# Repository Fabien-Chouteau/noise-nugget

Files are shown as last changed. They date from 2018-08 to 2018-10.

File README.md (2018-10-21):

# noise-nugget
Square Inch music widget

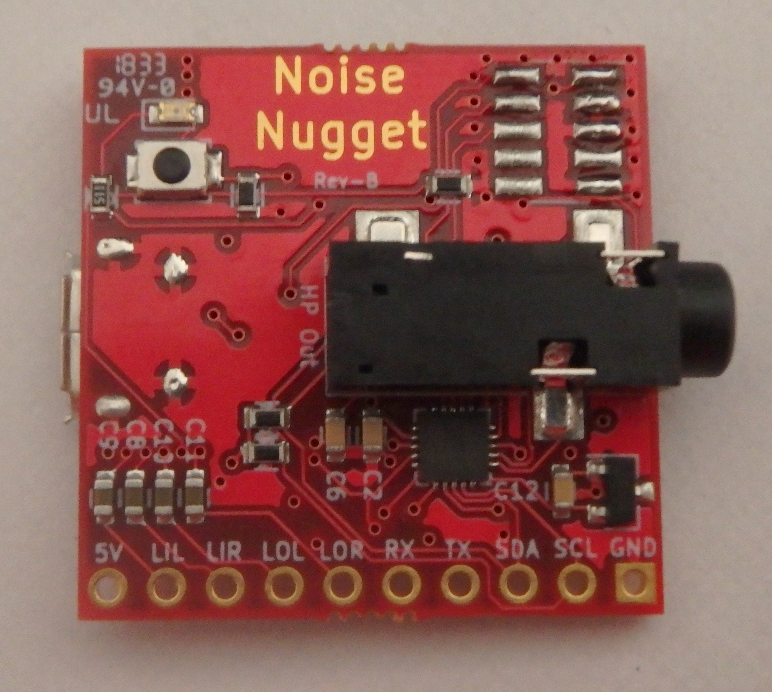
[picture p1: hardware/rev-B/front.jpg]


Noise Nugget is a compact digital synthesizer based on an 180MHz Cortex-M4 and
quality audio DAC with headphone amplifier.

My goal with this project is to create a little "Swiss Army knife" of audio
synthesis. Packing the maximum features on the smallest and cheapest board.

With all its connectivity (USB, 2 x audio out, 1 x audio in, I2C, UART, GPIOs)
it can be used for many different tasks:
 - Digital synthesizer, with a MIDI interface or some other means of control
 - Audio effects, for a guitar pedal or synthesizer (delay, reverb, distortion)
 - Audio FX trigger board, playing pre-recorded sounds
 - Audio playback, recording sounds from the input and then playing it back at
   the push of a button
 - USB sound interface

So far I implemented one audio effect, a MIDI over USB synth and sampler. Noise
Nugget is a compact digital synthesizer based on an 180MHz Cortex-M4 and
quality audio DAC with headphone amplifier.

My goal with this project is to create a little "Swiss Army knife" of audio
synthesis. Packing the maximum features on the smallest and cheapest board.

With all its connectivity (USB, 2 x audio out, 1 x audio in, I2C, UART, GPIOs)
it can be used for many different tasks:
- Digital synthesizer, with a MIDI interface or some other means of control
- Audio effects, for a guitar pedal or synthesizer (delay, reverb, distortion)
- Audio FX trigger board, playing pre-recorded sounds
- Audio playback, recording sounds from the input and then playing it back at
  the push of a button
- USB sound interface

So far I implemented one audio effect, a MIDI over USB synth and sampler.

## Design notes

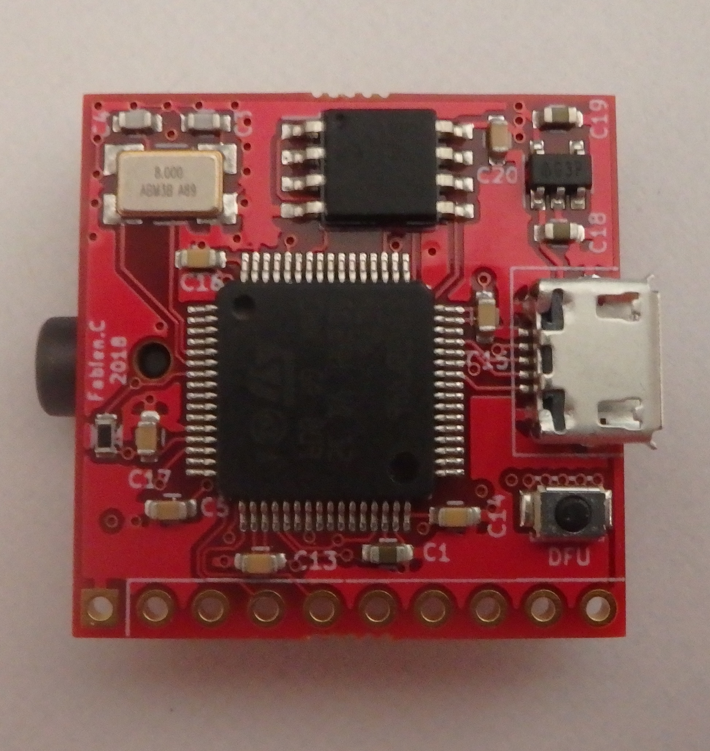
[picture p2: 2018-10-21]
hardware/rev-B/back.jpg

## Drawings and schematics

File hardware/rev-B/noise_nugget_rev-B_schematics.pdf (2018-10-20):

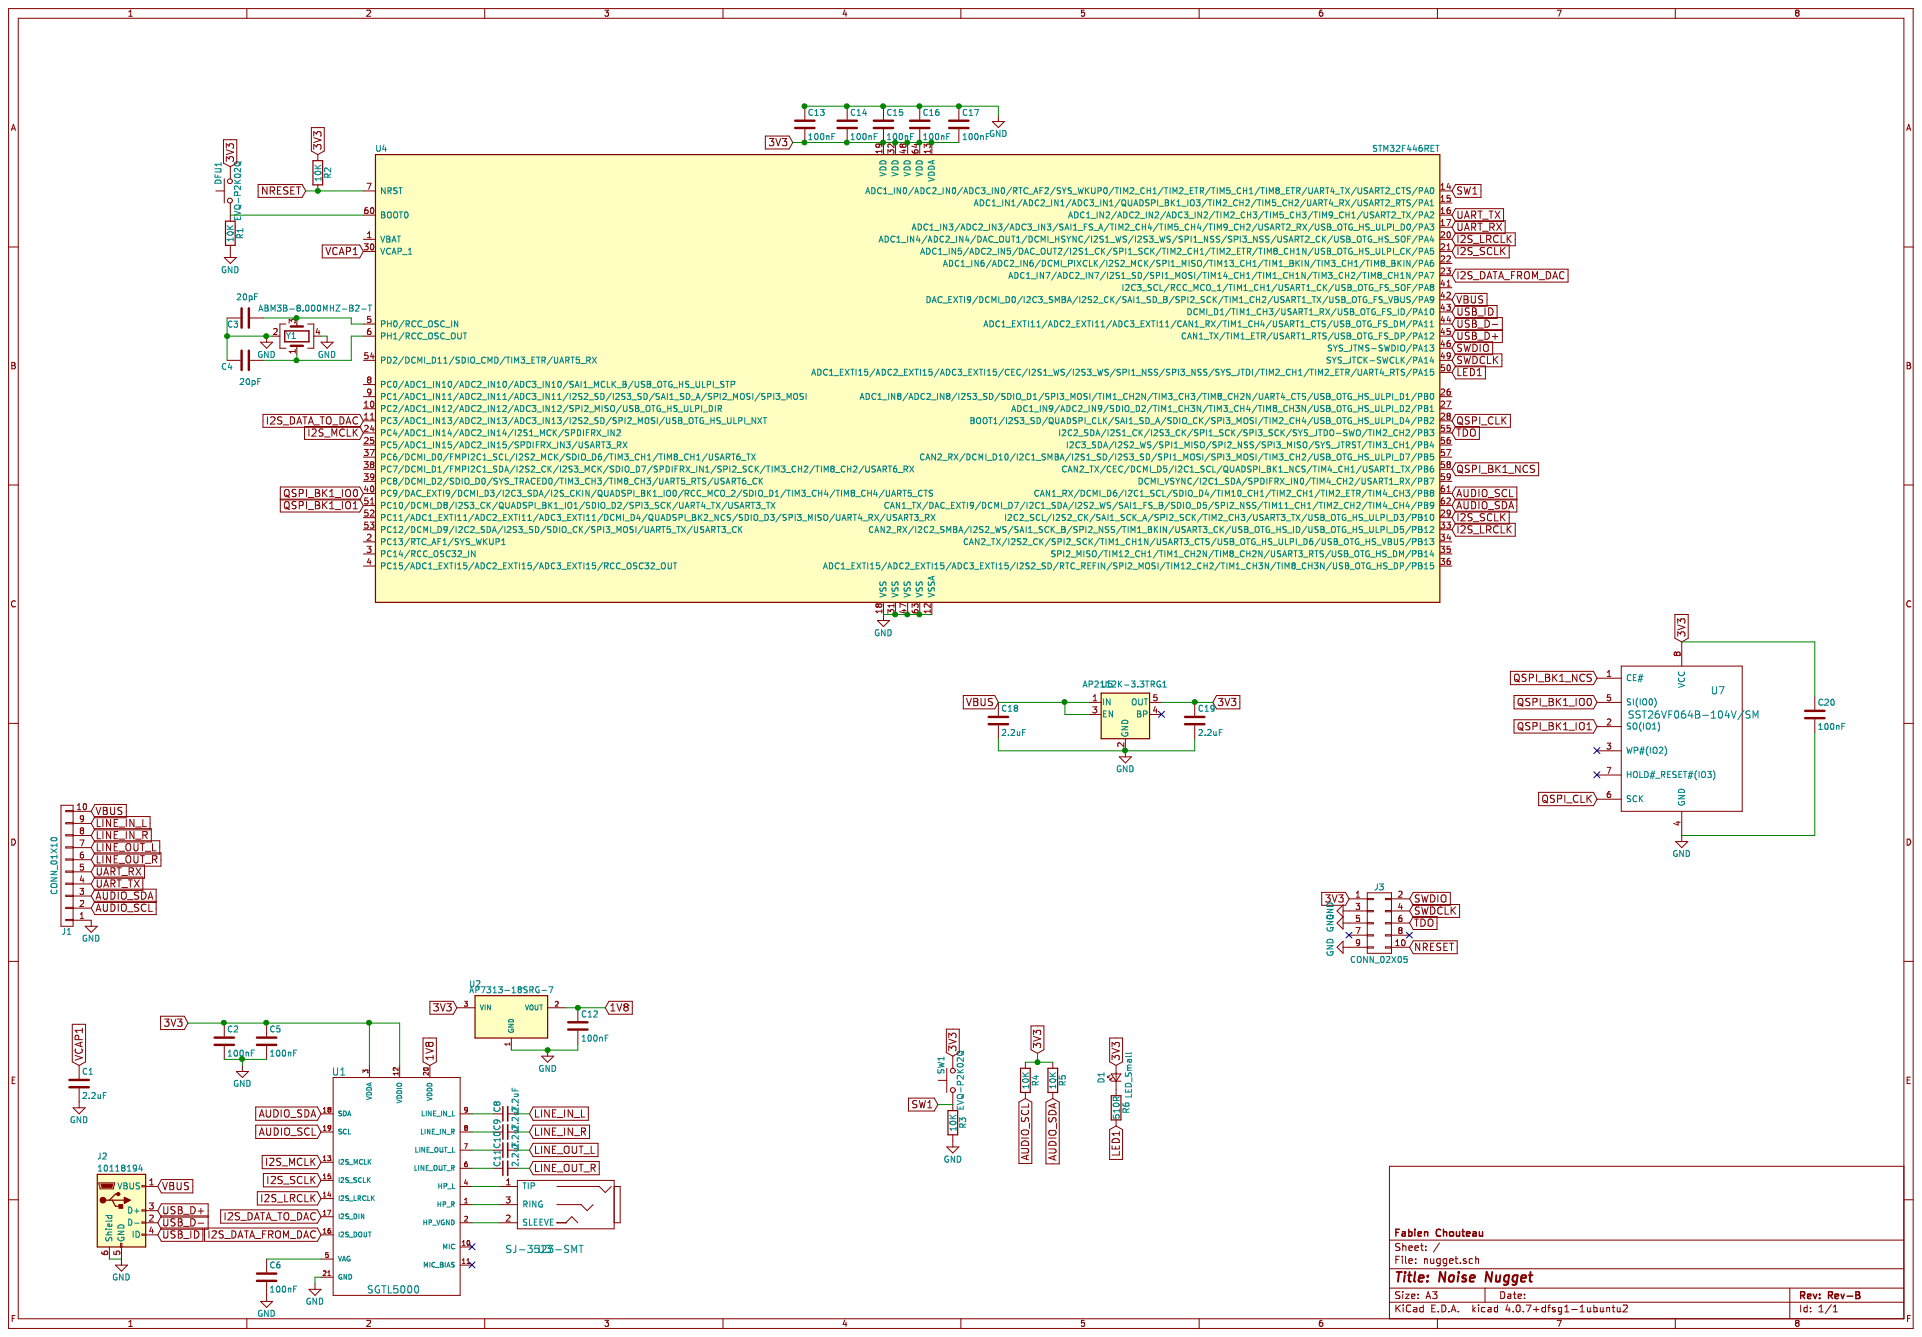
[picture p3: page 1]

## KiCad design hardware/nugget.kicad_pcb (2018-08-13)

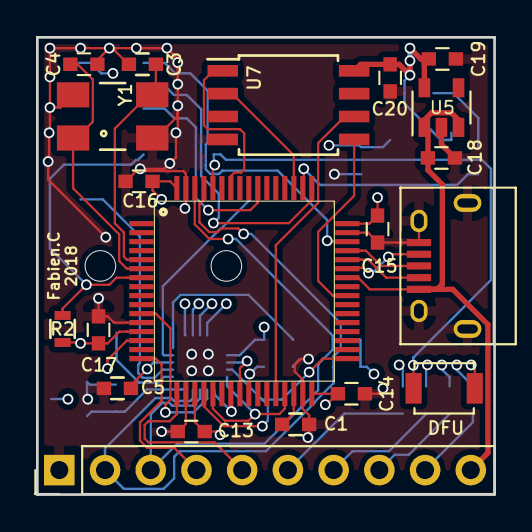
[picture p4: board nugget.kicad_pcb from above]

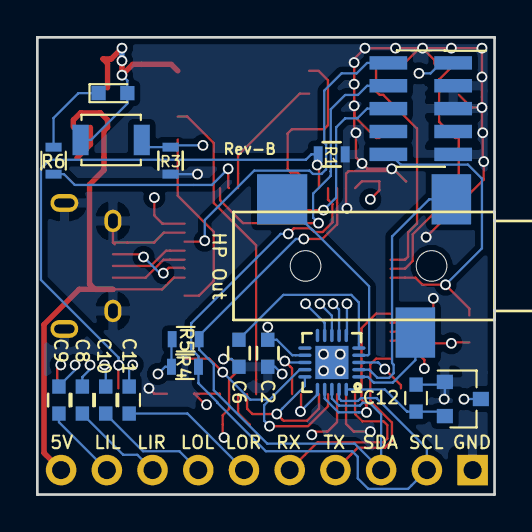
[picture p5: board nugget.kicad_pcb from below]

Board: 4 copper layers, 25.4 x 25.4 mm, 38 parts (18 on the bottom side), 43 nets.

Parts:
C1, C8, C9, C10, C11, C18, C19: 2.2uF; C_0603
C2, C5, C6, C12, C13, C14, C15, C16, C17, C20: 100nF; C_0603
C3, C4: 20pF; C_0603
D1: LED_Small; LED_0603
DFU1: EVQ-P2K02Q; SW_SPST_B3U-1000P
J1: CONN_01X10; Pin_Header_Straight_1x10_Pitch2.54mm
J2: 10118194; USB_Micro-B
J3: CONN_02X05; Socket_Strip_Straight_2x05_Pitch1.27mm_SMD
R1, R2, R3, R4, R5: 10K; R_0603
R6: 510R; R_0603
SW1: EVQ-P2K02Q; SW_SPST_B3U-1000P
U1: SGTL5000; UQFN-20-1EP_3x3mm_Pitch0.4mm
U2: AP7313-18SRG-7; SOT-23
U3: SJ-3523-SMT
U4: STM32F446RET; LQFP64
U5: AP2112K-3.3TRG1; SOT-23-5
U7: SST26VF064B-104V/SM; SOIJ-8_5.3x5.3mm_Pitch1.27mm
Y1: ABM3B-8.000MHZ-B2-T; Crystal_SMD_0603_4Pads

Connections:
1V8: C12.1, U1.20, U2.2
3V3: C2.1, C5.1, C13.2, C14.2, C15.2, C16.2, C17.2, C19.1, C20.1, D1.2, DFU1.2, J3.1, R2.1, R4.1, R5.1, SW1.2, U1.3, U1.12, U2.3, U4.13, U4.19, U4.32, U4.48, U4.64, U5.5, U7.8
AUDIO_SCL: J1.2, R4.2, U1.19, U4.61
AUDIO_SDA: J1.3, R5.2, U1.18, U4.62
GND: C1.2, C2.2, C3.2, C4.2, C5.2, C6.2, C12.2, C13.1, C14.1, C15.1, C16.1, C17.1, C18.2, C19.2, C20.2, J1.1, J2.5, J2.6, J3.3, J3.5, J3.9, R1.2, R3.2, U1.21, U2.1, U4.12, U4.18, U4.31, U4.47, U4.63, U5.2, U7.4, Y1.2, Y1.4
I2S_DIN: U1.17, U4.11
I2S_DOUT: U1.16, U4.23
I2S_LRCLK: U1.14, U4.20, U4.33
I2S_MCLK: U1.13, U4.24
I2S_SCLK: U1.15, U4.21, U4.29
LED1: R6.2, U4.50
LINE_IN_L: C8.2, J1.9
LINE_IN_R: C9.2, J1.8
LINE_OUT_L: C10.2, J1.7
LINE_OUT_R: C11.2, J1.6
NRESET: J3.10, R2.2, U4.7
unnamed: C3.1, U4.5, Y1.3
unnamed: C4.1, U4.6, Y1.1
unnamed: C6.1, U1.5
unnamed: C8.1, U1.9
unnamed: C9.1, U1.8
unnamed: C10.1, U1.7
unnamed: C11.1, U1.6
unnamed: D1.1, R6.1
unnamed: DFU1.1, R1.1, U4.60
unnamed: U1.1, U3.3
unnamed: U1.2, U3.2
unnamed: U1.4, U3.1
QSPI_BK1_IO0: U4.40, U7.5
QSPI_BK1_IO1: U4.51, U7.2
QSPI_BK1_NCS: U4.58, U7.1
QSPI_CLK: U4.28, U7.6
SW1: R3.1, SW1.1, U4.14
SWDCLK: J3.4, U4.49
SWDIO: J3.2, U4.46
TDO: J3.6, U4.55
UART_RX: J1.5, U4.17
UART_TX: J1.4, U4.16
USB_D+: J2.3, U4.45
USB_D-: J2.2, U4.44
USB_ID: J2.4, U4.43
VBUS: C18.1, J1.10, J2.1, U4.42, U5.1, U5.3
VCAP1: C1.1, U4.30

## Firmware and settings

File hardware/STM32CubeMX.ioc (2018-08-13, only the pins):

Mcu.UserName=STM32F446RETx
PA10.Signal=USB_OTG_FS_ID
PA11.Signal=USB_OTG_FS_DM
PA12.Signal=USB_OTG_FS_DP
PA2.Signal=USART2_TX
PA3.Signal=USART2_RX
PA4.Signal=I2S1_WS
PA5.Signal=I2S1_CK
PA7.Signal=I2S1_SD
PA9.Signal=USB_OTG_FS_VBUS
PB10.Signal=I2S2_CK
PB12.Signal=I2S2_WS
PB2.Signal=QUADSPI_CLK
PB6.Signal=QUADSPI_BK1_NCS
PC10.Signal=QUADSPI_BK1_IO1
PC3.Signal=I2S2_SD
PC4.Signal=I2S1_MCK
PC9.Signal=QUADSPI_BK1_IO0
PH0-OSC_IN.Signal=RCC_OSC_IN
PH1-OSC_OUT.Signal=RCC_OSC_OUT

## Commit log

2018-08-13 Noise Nugger rev-B
    [nugget-B.Cu.gbl, nugget-B.Mask.gbs, nugget-B.Paste.gbp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]
2018-09-30 Switch to my version of ADL with proto USB support
2018-10-07 Add sampler mode (#1)
2018-10-20 Add rev-B schematics
